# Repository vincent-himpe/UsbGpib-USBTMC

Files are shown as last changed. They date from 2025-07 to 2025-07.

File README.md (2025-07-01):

# GPIB-USBTMC Adapter 

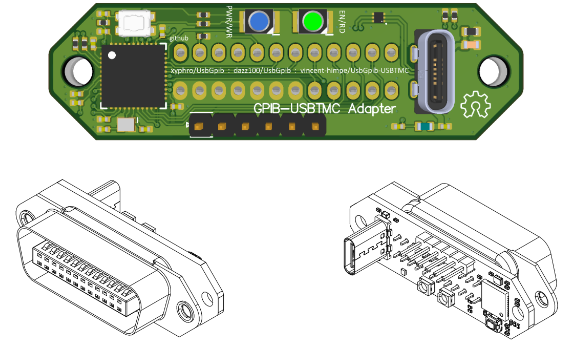
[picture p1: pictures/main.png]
What is this


## Project Introduction

This project is based on the popular Xyphro USB-GPIB adapter https://github.com/xyphro/UsbGpib 

and the fork created by Dazz100  https://github.com/dazz100/UsbGpib .

The enhancements of this design are purely hardware. I did not do any software modifications and both Xypro and Daz100 can run.

Modifications :

1. Used a thru-hole, vertical USB-C connector for mechanical robustness. SMD connectors break too easy.
2. Optimized BOM to use LCSC parts so the JLCPCB service can be used to make and assemble the board.
3. Single sided SMD placement for cost optimisation. GPIB connector and USB connector thru-hole and to be soldered by end user.
4. Changed the GPIB connector to a vertical, thru-hole connector
5. Board shape designed to fit directly behind the GPIB conector without protrusions. The board is the size of the connector shell.
6. Changed CPU to QFN version and most components to 0402.
7. Changed one LED to BLUE for colorblind people like me. Red/Green is the most common colorblindness.
8. Added Reset button

This repository includes the hardware and software files to build this version.
The software is a clone from the DAZ100 firmware as it stood on 06/29/2025.
You may want to check the Xypro and DAZ100 repositories for updates to the firmware.

## PCB

The project was recreated in Altium V25

The production pack (Gerber, NCDrill, Pick&Place and BOM) for JLCPCB is included in a single ZIP file.
The schematic and fabrication, assembly information is exported as PDF.

All source files (Altium V25) are provided. Most other CAD tools can import those, or you import the Gerber/NC drill.

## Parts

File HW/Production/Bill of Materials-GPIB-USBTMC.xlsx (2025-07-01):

Description | Designator | Quantity | LCSC
CAPACITOR,CERAMIC,100nF,16V,X7R,0402 | C1, C4, C5, C10 | 4 | C60474
CAPACITOR,CERAMIC,15pF,50V,C0G,0402 | C2, C3 | 2 | C3906764
CAPACITOR,CERAMIC,1uF,10V,X7R,0402 | C6 | 1 | C528974
CAPACITOR,CERAMIC,4u7,10V,X5R,0402 | C7, C8, C9, C12, C13 | 5 | C23733
CAPACITOR,CERAMIC,1nF,250V,X7R,0603 | C11 | 1 | C277510
TVS,USB,BOURNS,CDDFN6-3312P | D1 | 1 | C3700524
LED,GREEN,PLCC2 | D2 | 1 | C5248446
LED,BLUE,PLCC2 | D4 | 1 | C6323026
FERRITE,1KZ@100MHz,0R2DC,0603 | FB1 | 1 | C160982
CONN,USB-C,VERTICAL,TH, CONN,PINHEADER,1X6,2.45MM,VERT,GOLD, CONN,GPIB,24P,VERT,TH | J1, J2, P1 | 3
RESISTOR,100K,1%,63mW,0402 (1005) | R1 | 1 | C60491
RESISTOR,4K7,1%,100mW,0603 (1608) | R2 | 1 | C99782
RESISTOR,10K,1%,63mW,0402 (1005) | R3 | 1 | C60490
RESISTOR,27R,1%,63mW,0402 (1005) | R4, R6 | 2 | C138021
RESISTOR,1K,1%,63mW,0402 (1005) | R5, R7 | 2 | C106235
RESISTOR,5K1,1%,63mW,0402 (1005) | R8, R9 | 2 | C105872
SW,SMD,TACT,4PIN,2.9X3.5,4PIN | SW1 | 1 | C483888
IC,CPU,ATMEG32U4-MU,QFN44 | U1 | 1 | C45874
XTAL,16MHz,2016,4P | X1 | 1 | C2965579

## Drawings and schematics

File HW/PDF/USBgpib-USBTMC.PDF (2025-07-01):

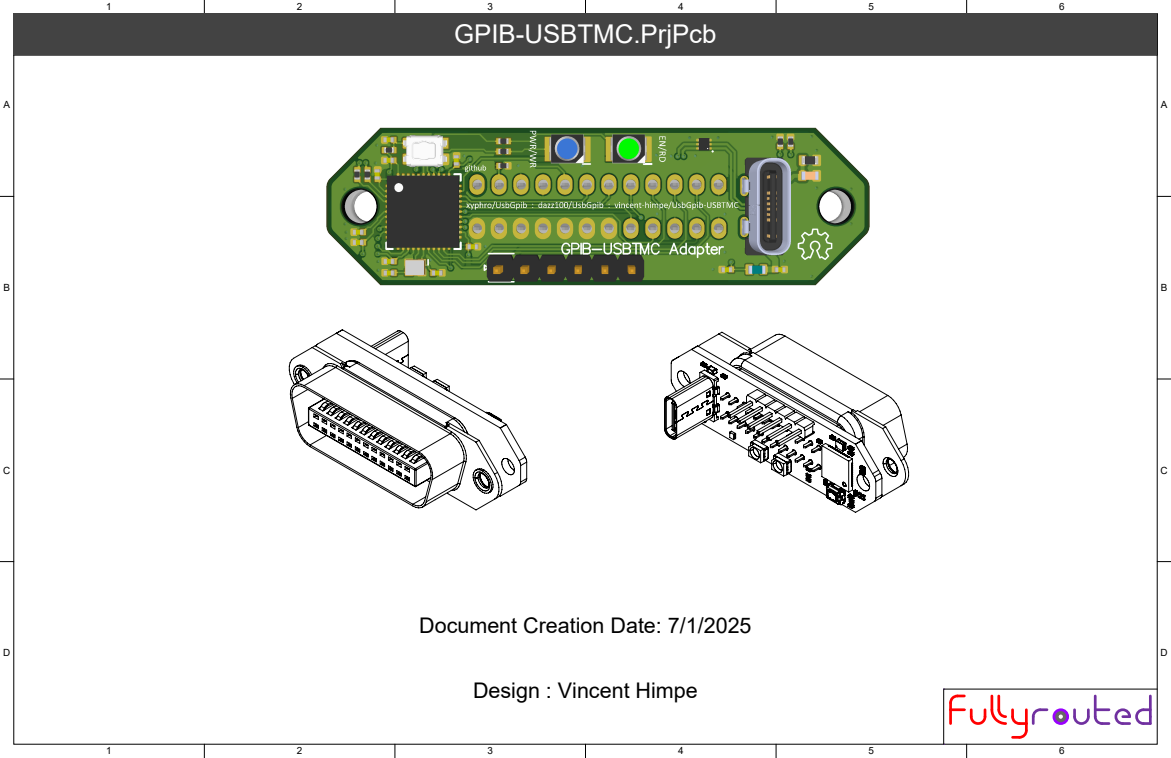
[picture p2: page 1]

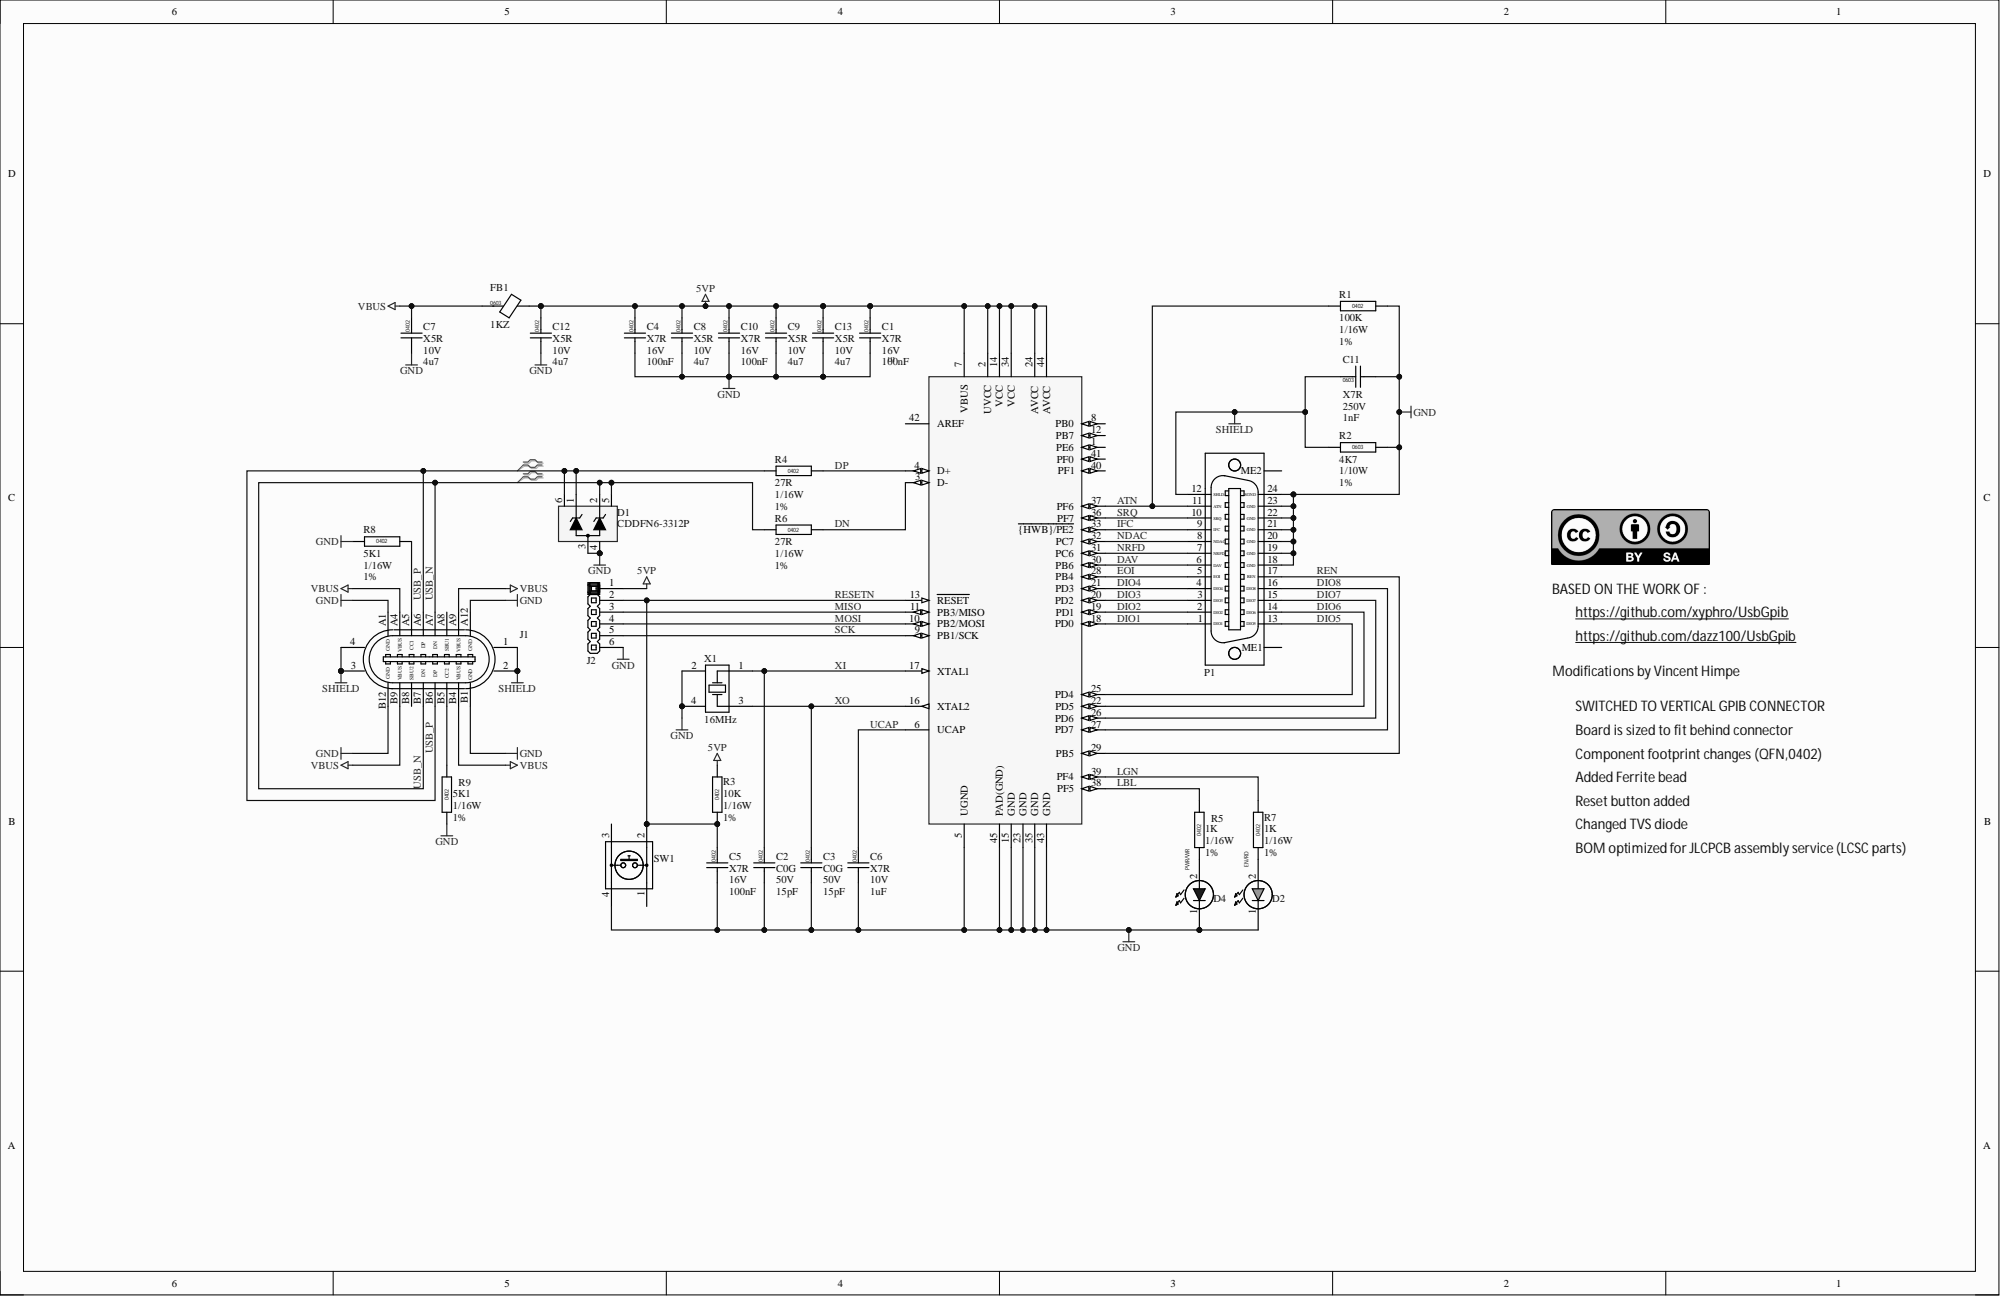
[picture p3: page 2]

21 0 PD3 | DIO 4 4 | O4 | | DIO 8

2 | DIO 3 3 | DI O3 | | DIO 7

BASED ON THE WORK OF : https://github.com/daz

MISO 1 1 | 19 8 PD1 | 2 DIO 2 | DI | DIO 6

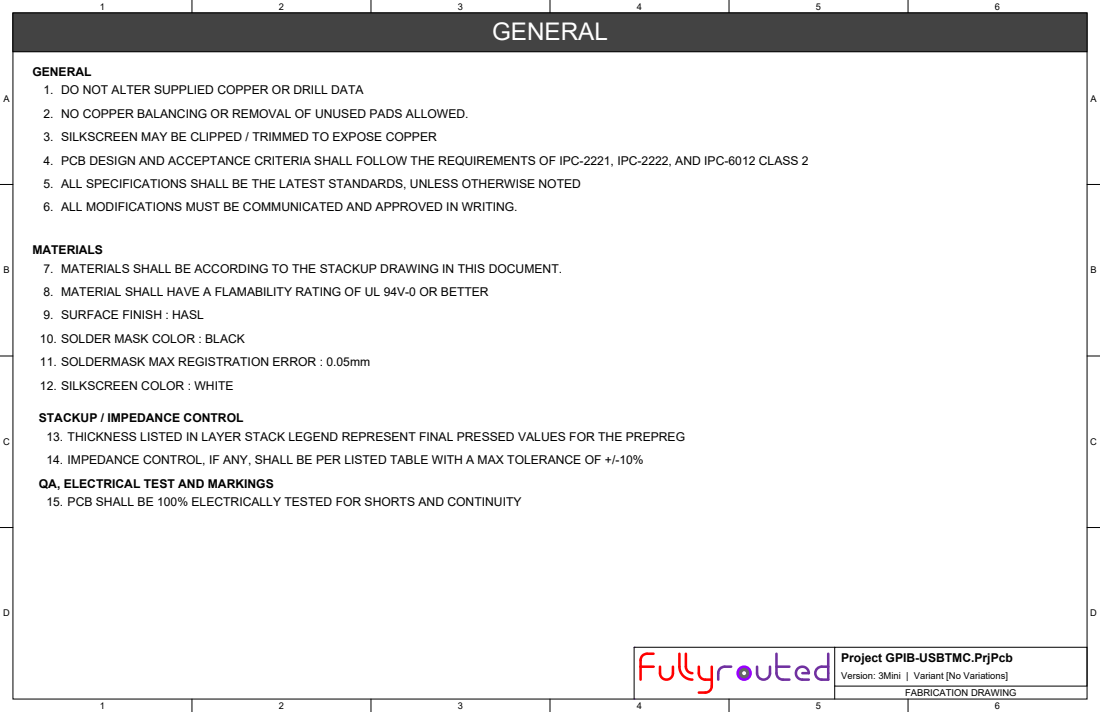
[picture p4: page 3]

GENERAL
1. DO NOT ALTER SUPPLIED COPPER OR DRILL DATA
2. NO COPPER BALANCING OR REMOVAL OF UNUSED PADS ALLOWED.
3. SILKSCREEN MAY BE CLIPPED / TRIMMED TO EXPOSE COPPER
4. PCB DESIGN AND ACCEPTANCE CRITERIA SHALL FOLLOW THE REQUIREMENTS OF IPC-2221, IPC-2222, AND IPC-6012 CLASS 2
5. ALL SPECIFICATIONS SHALL BE THE LATEST STANDARDS, UNLESS OTHERWISE NOTED
6. ALL MODIFICATIONS MUST BE COMMUNICATED AND APPROVED IN WRITING.

MATERIALS
7. MATERIALS SHALL BE ACCORDING TO THE STACKUP DRAWING IN THIS DOCUMENT.
8. MATERIAL SHALL HAVE A FLAMABILITY RATING OF UL 94V-0 OR BETTER
9. SURFACE FINISH : HASL
10. SOLDER MASK COLOR : BLACK
11. SOLDERMASK MAX REGISTRATION ERROR : 0.05mm
12. SILKSCREEN COLOR : WHITE

STACKUP / IMPEDANCE CONTROL
13. THICKNESS LISTED IN LAYER STACK LEGEND REPRESENT FINAL PRESSED VALUES FOR THE PREPREG
14. IMPEDANCE CONTROL, IF ANY, SHALL BE PER LISTED TABLE WITH A MAX TOLERANCE OF +/-10%
QA, ELECTRICAL TEST AND MARKINGS
15. PCB SHALL BE 100% ELECTRICALLY TESTED FOR SHORTS AND CONTINUITY

Project GPIB-USBTMC.PrjPcb
Version: 3Mini | Variant [No Variations]

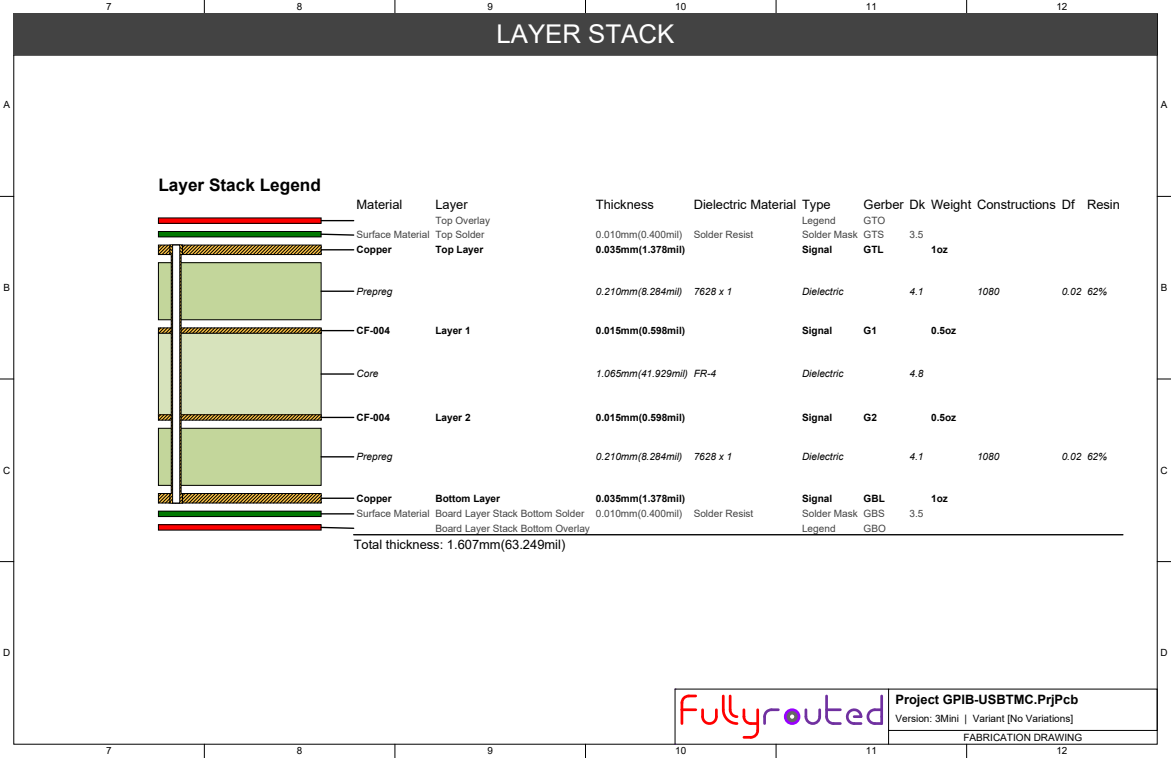
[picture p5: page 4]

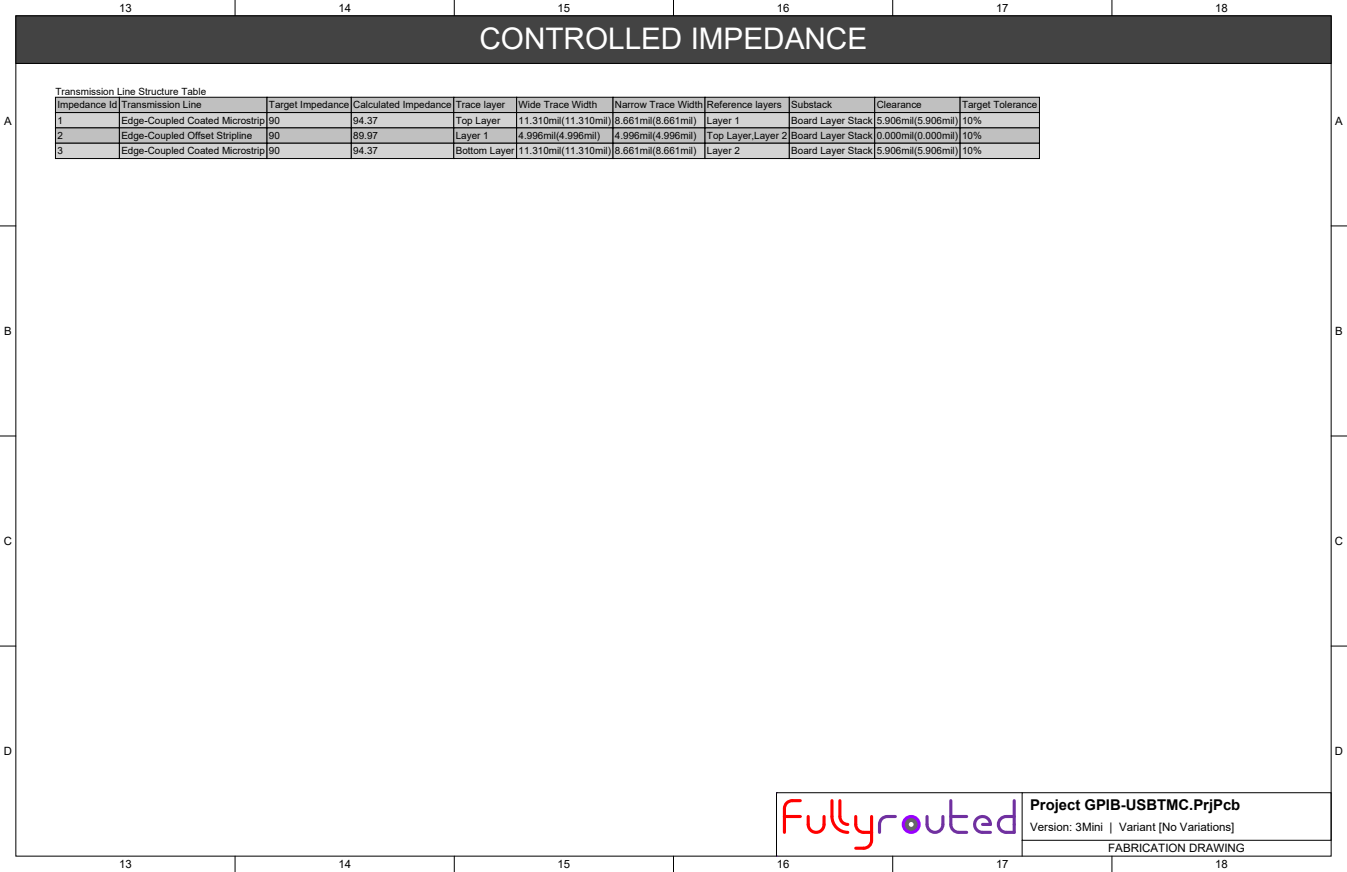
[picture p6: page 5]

Transmission Line Structure Table

Impedance Id | Transmission Line | Target Impedance | Calculated Impedance | Trace layer | Wide Trace Width | Narrow Trace Width | Reference layers | Substack | Clearance | Target Tolerance
1 | Edge-Coupled Coated Microstrip | 90 | 94.37 | Top Layer | 11.310mil(11.310mil) | 8.661mil(8.661mil) | Layer 1 | Board Layer Stack | 5.906mil(5.906mil) | 10%
2 | Edge-Coupled Offset Stripline | 90 | 89.97 | Layer 1 | 4.996mil(4.996mil) | 4.996mil(4.996mil) | Top Layer,Layer 2 | Board Layer Stack | 0.000mil(0.000mil) | 10%
3 | Edge-Coupled Coated Microstrip | 90 | 94.37 | Bottom Layer | 11.310mil(11.310mil) | 8.661mil(8.661mil) | Layer 2 | Board Layer Stack | 5.906mil(5.906mil) | 10%

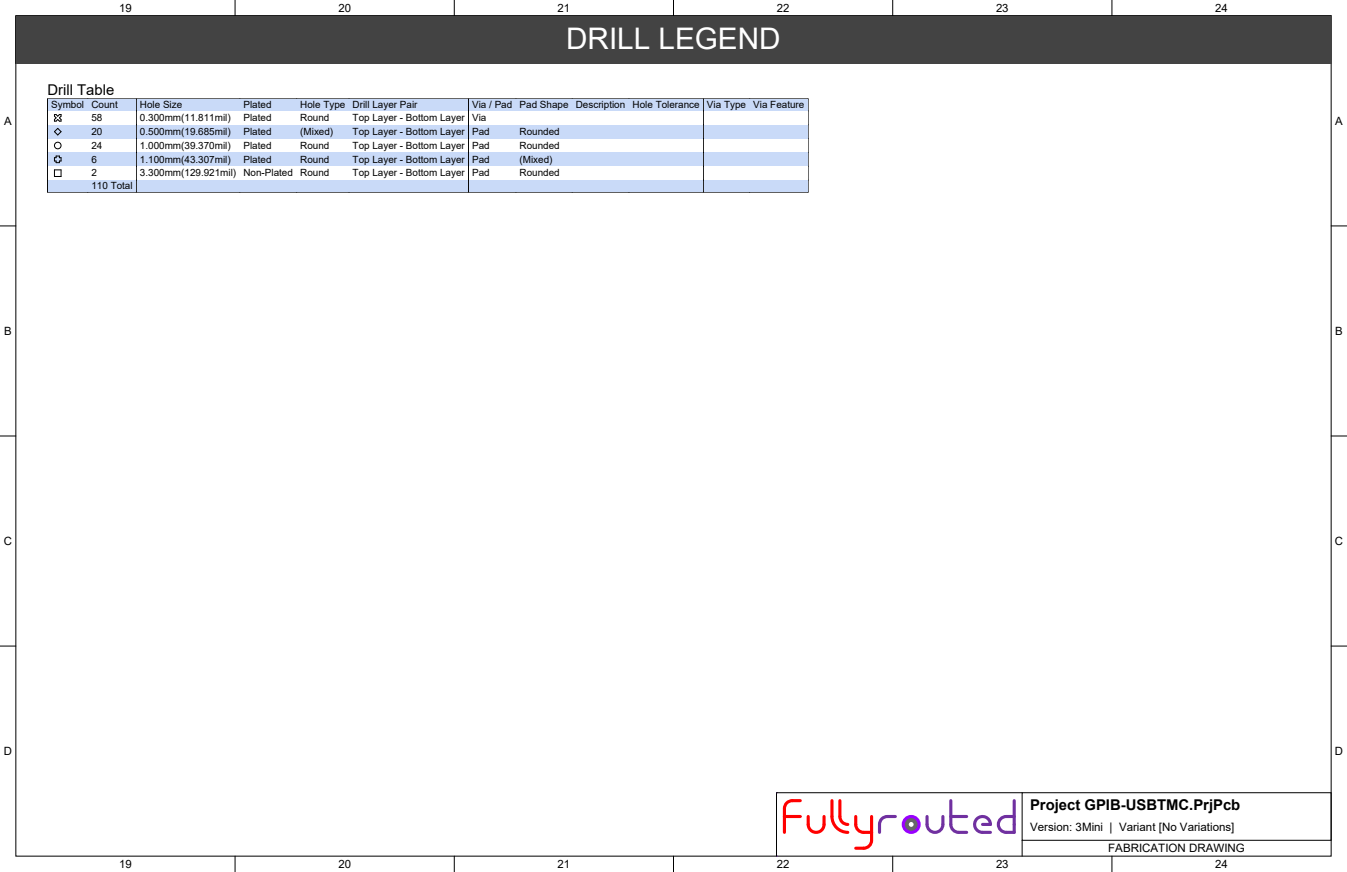
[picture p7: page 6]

Symbol | Count | Hole Size | Plated | Hole Type | Drill Layer Pair | Via / Pad | Pad Shape | Description | Hole Tolerance | Via Type | Via Feature

58 | 0.300mm(11.811mil) | Plated | Round | Top Layer - Bottom Layer | Via
20 | 0.500mm(19.685mil) | Plated | (Mixed) | Top Layer - Bottom Layer | Pad | Rounded
24 | 1.000mm(39.370mil) | Plated | Round | Top Layer - Bottom Layer | Pad | Rounded
6 | 1.100mm(43.307mil) | Plated | Round | Top Layer - Bottom Layer | Pad | (Mixed)
2 | 3.300mm(129.921mil) | Non-Plated | Round | Top Layer - Bottom Layer | Pad | Rounded
110 Total

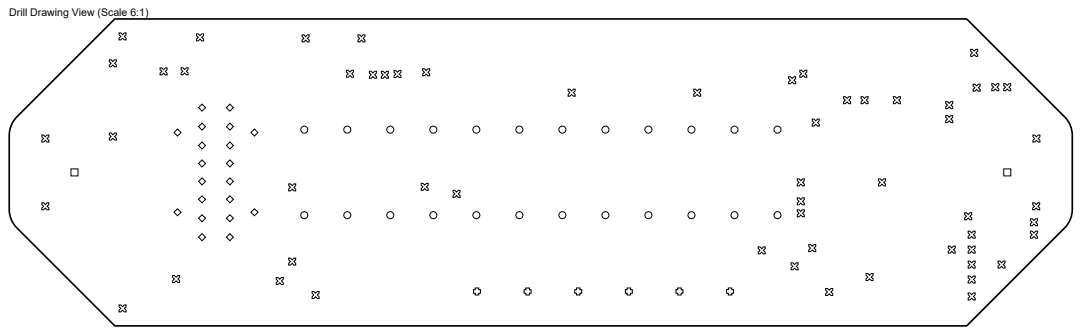
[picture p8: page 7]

Drill Drawing View (Scale 6:1)

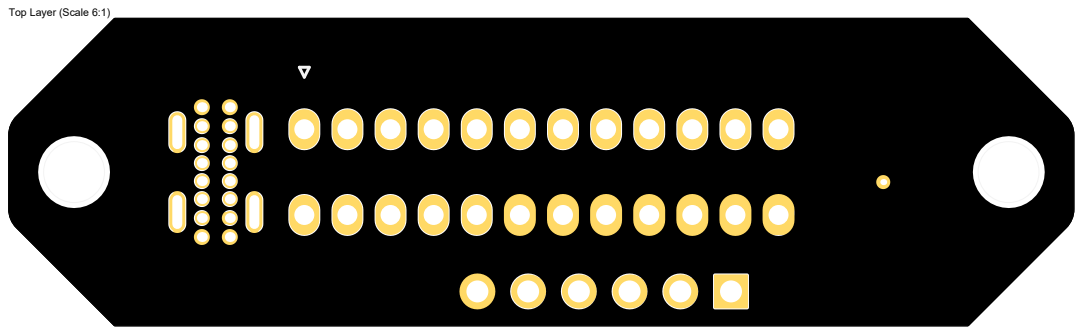
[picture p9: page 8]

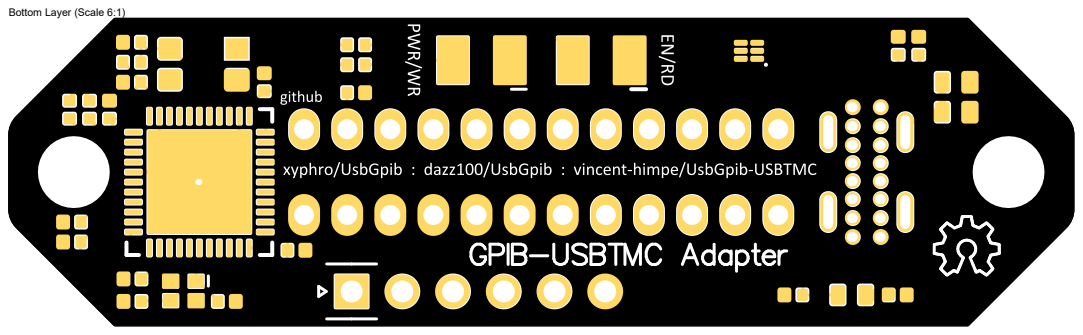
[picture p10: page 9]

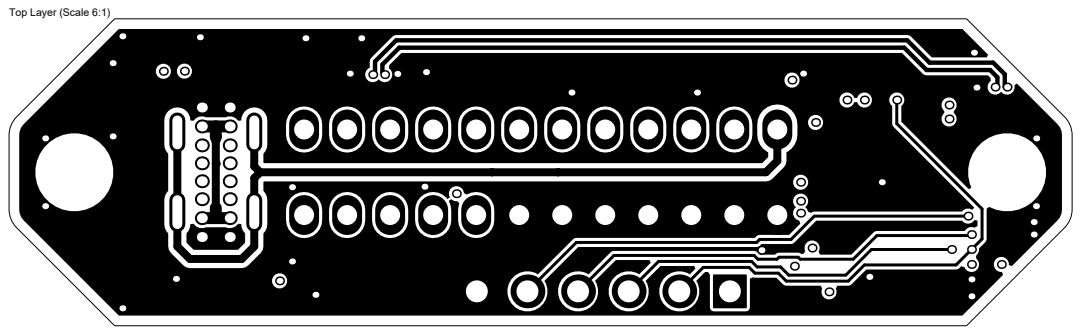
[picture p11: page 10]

LAYER VIEW : TOP LAYER

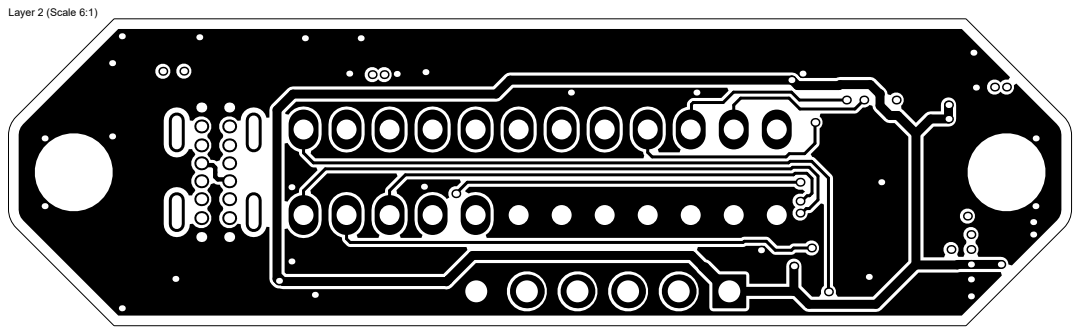
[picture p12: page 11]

LAYER VIEW : MID LAYER 1

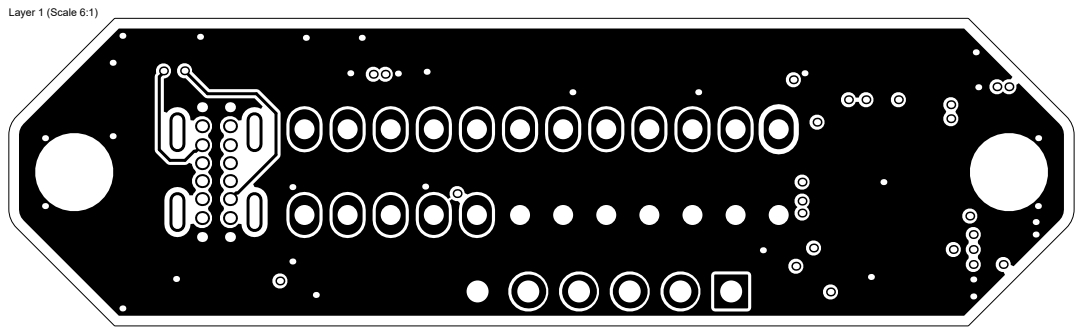
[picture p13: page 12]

LAYER VIEW : MID LAYER 2


LAYER VIEW : BOTTOM LAYER


LAYER VIEW : TOP SOLDER MASK


LAYER VIEW : BOTTOM SOLDER MASK

Board Layer Stack Bottom Solder (Scale 6:1)


LAYER VIEW : TOP SILKSCREEN (LEGEND)


LAYER VIEW : BOTTOM SILKSCREEN (LEGEND)

Board Layer Stack Bottom Overlay (Scale 6:1)


Unless otherwise specified the following rules apply:
1. DO NOT DEVIATE FROM ARTWORK OR BOM WITHOUT PRIOR AUTHORIZATION.
2. ASSEMBLE AND INSPECT PER IPC-610 CLASS 2

Bill of Materials and Material Handling
3. THE BOM CONTAINED IN THIS DOCUMENT IS AS-BUILT. NON-INSTALLED PARTS HAVE BEEN REMOVED. ADDITIONAL BOM FORMATS ARE AVAILABLE IN THE PROJECT FILES
4. ANY PART SUBSTITUTIONS MUST BE APPROVED IN WRITING BEFORE ASSEMBLY
5. ALL MATERIALS MUST BE PROCURED FROM MANUFACTURER AUTHORIZED DISTRIBUTORS OR THE ORIGINAL MANUFACTURER
6. ALL COMPONENTS AND BOARDS TO BE HANDLED AND STORED ACCORDING TO IPC GUIDELINES
7. ESD CONTROL PER IPC RULES

Soldering
8. SOLDERING TO BE DONE USING SN37PB63 ALLOY USING ALLOY MANUFACTURER RECOMMENDED NO-CLEAN FLUX
9. BGA COMPONENTS WITH LEAD-FREE CONNECTIONS NEED TO BE REBALLED WITH SN63PB37. MIXING OF ALLOYS IS NOT PERMITTED.
10. SOLDERING PREFERRABLY TO BE DONE USING NITROGEN ATMOSPHERE
11. SURPLUS COMPONENTS TO VACUUM SEALED WITH DESSICANT IN ANTISTATIC BAGS
12. INCOMING MATERIAL (BOARDS AND COMPONENTS) NEEDS TO BE INSPECTED FOR HUMIDITY AND BAKED IF NEEDED PRIOR TO USE.
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

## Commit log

2025-07-01 TRIAL 1
    [Bill of Materials-USBgpib-V3-USBTMC.csv, Bill of Materials-USBgpib-V3-USBTMC.xlsx, Bill of Materials-USBgpib-v3-USBTMC.csv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]
2025-07-01 PUSH BEFORE CLEANUP
    [USBgpib-USBTMC-V3mini.PrjPcb, USBgpib-V3-USBTMC.PcbDoc, USBgpib-v3-USBTMC.SchDoc]
2025-07-01 CLEANUP AND PRODUCTION RELEASE
    [Bill of Materials-GPIB-USBTMC.csv, Bill of Materials-GPIB-USBTMC.xlsx, Bill of Materials-USBgpib-V3-USBTMC.csv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]
